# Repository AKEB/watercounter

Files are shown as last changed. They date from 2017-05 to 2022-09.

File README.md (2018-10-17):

# README #

Простая плата на базе микросхемы ESP8266 (Wemos D1 mini). Плата считает кол-во импульсов от счетчиков воды (горячей и холодной) и импульс от системы АкваСторож.
Отображение в web интерфейсе и отправка на сервер умного дома по протоколу MQTT

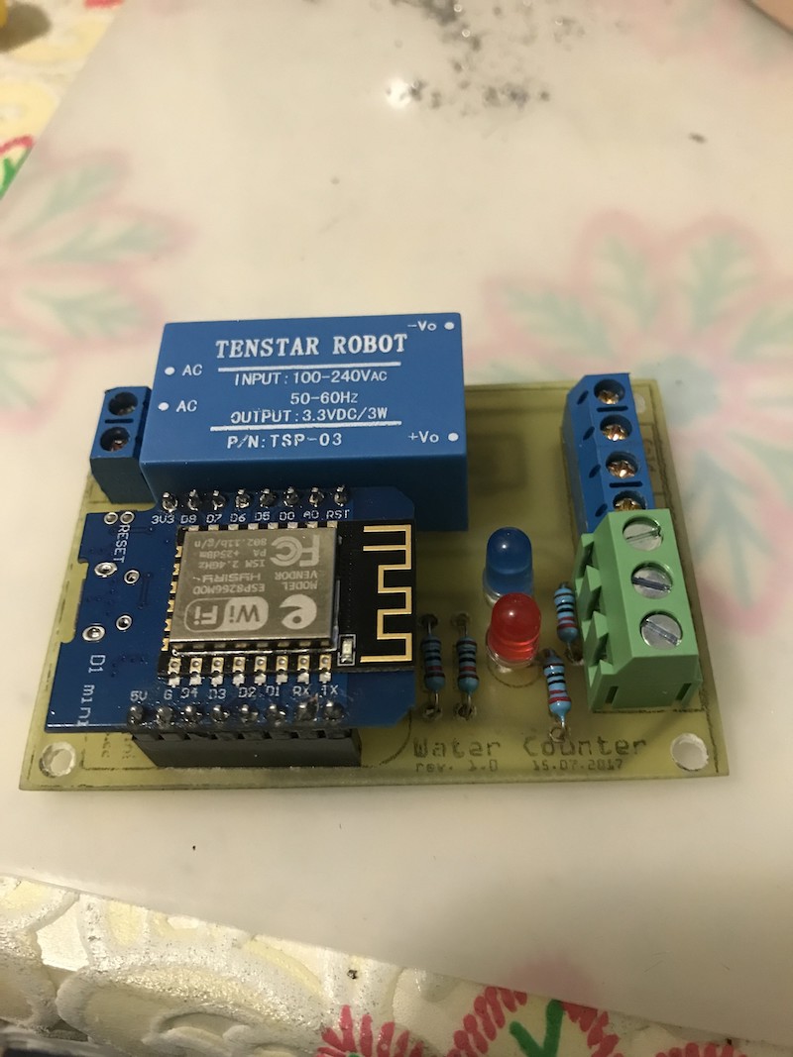
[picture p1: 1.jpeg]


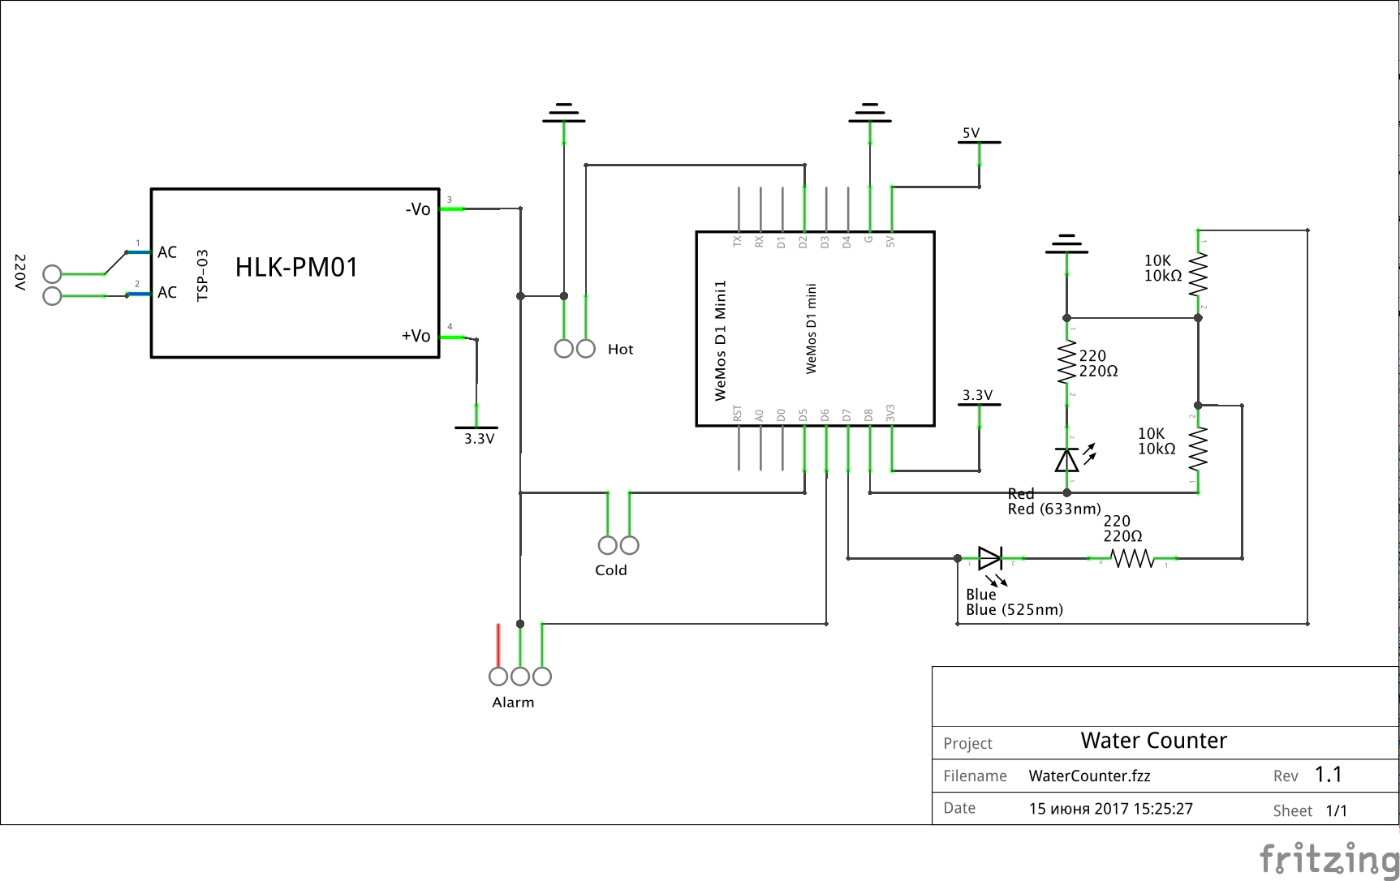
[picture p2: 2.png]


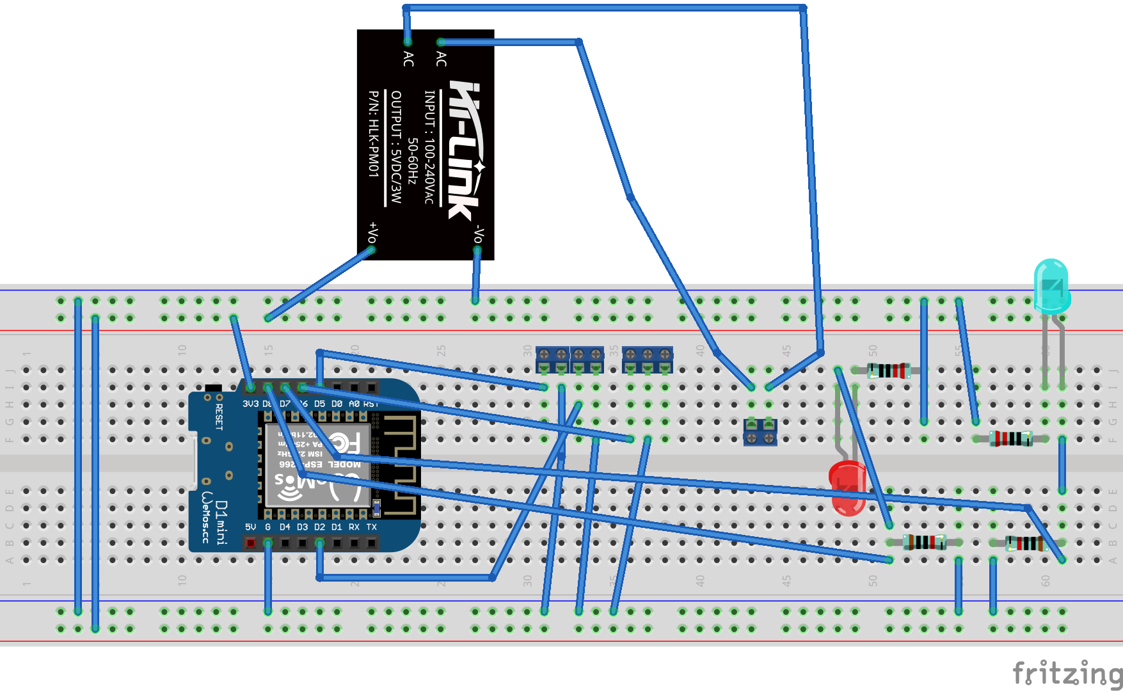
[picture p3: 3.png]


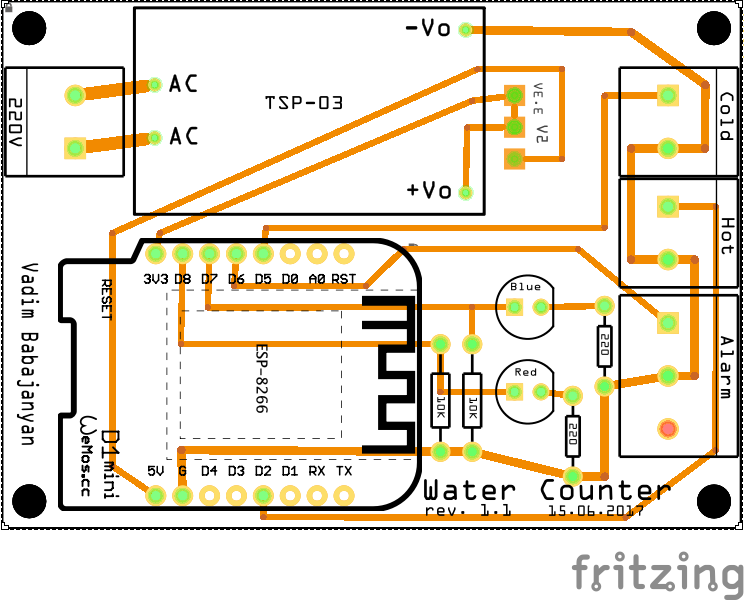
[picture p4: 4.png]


File System install https://github.com/esp8266/arduino-esp8266fs-plugin

# Распиновка #
* Красная лампа - D8 - GPIO15
* Синяя лампа - D7 - GPIO13
* Встроенная лампа - D4 - GPIO2
* Холодная вода - D5 - GPIO14
* Горячая вода - D2 - GPIO4
* ALARM - D6 - GPIO12

## Ссылки ##
* [esptool-gui](https://github.com/Rodmg/esptool-gui)
* [esptool](https://github.com/espressif/esptool)

## Код для заливки прошивки ##
```
#!bash

./esptool.py --port /dev/cu.wchusbserial1420 write_flash -fm=dio -fs=4MB 0x00000 ~/Downloads/0x00000_ESP8266_201705062105.bin

```

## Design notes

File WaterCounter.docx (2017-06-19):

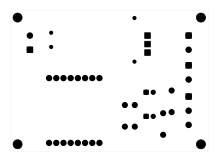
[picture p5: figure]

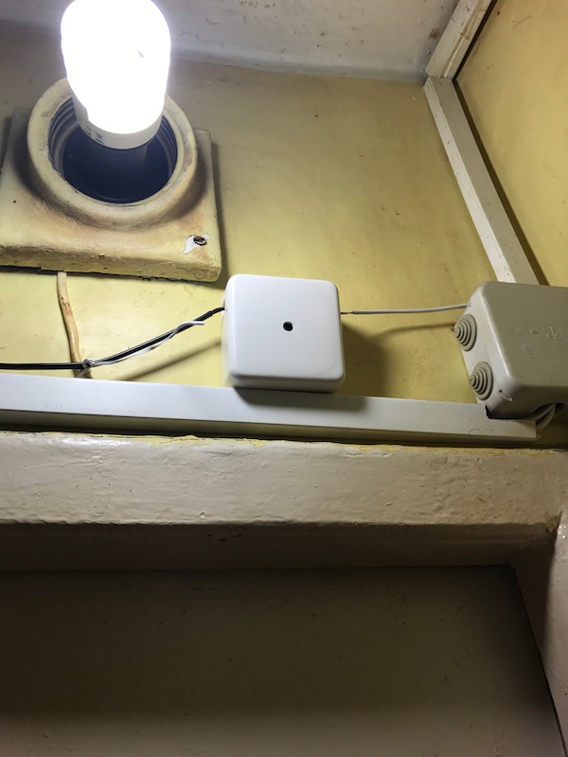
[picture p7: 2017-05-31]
Photos/IMG_0181.JPG.jpeg

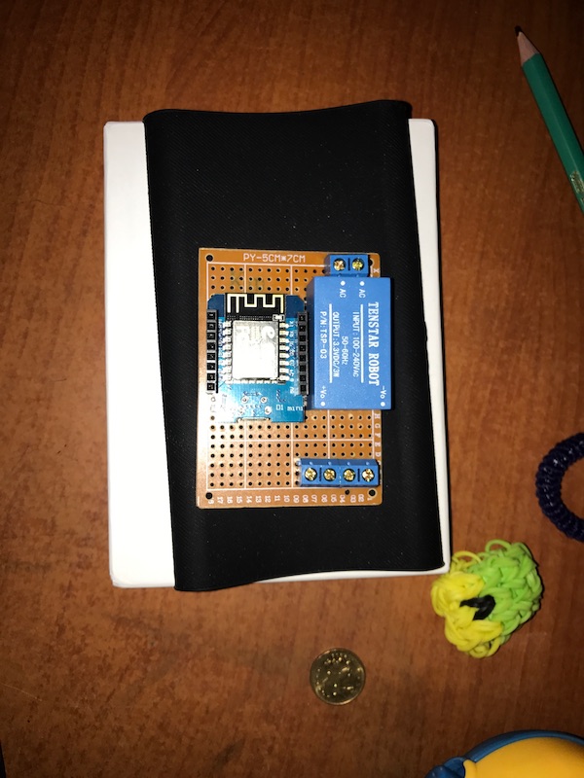
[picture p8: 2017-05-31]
Photos/IMG_0149.JPG.jpeg

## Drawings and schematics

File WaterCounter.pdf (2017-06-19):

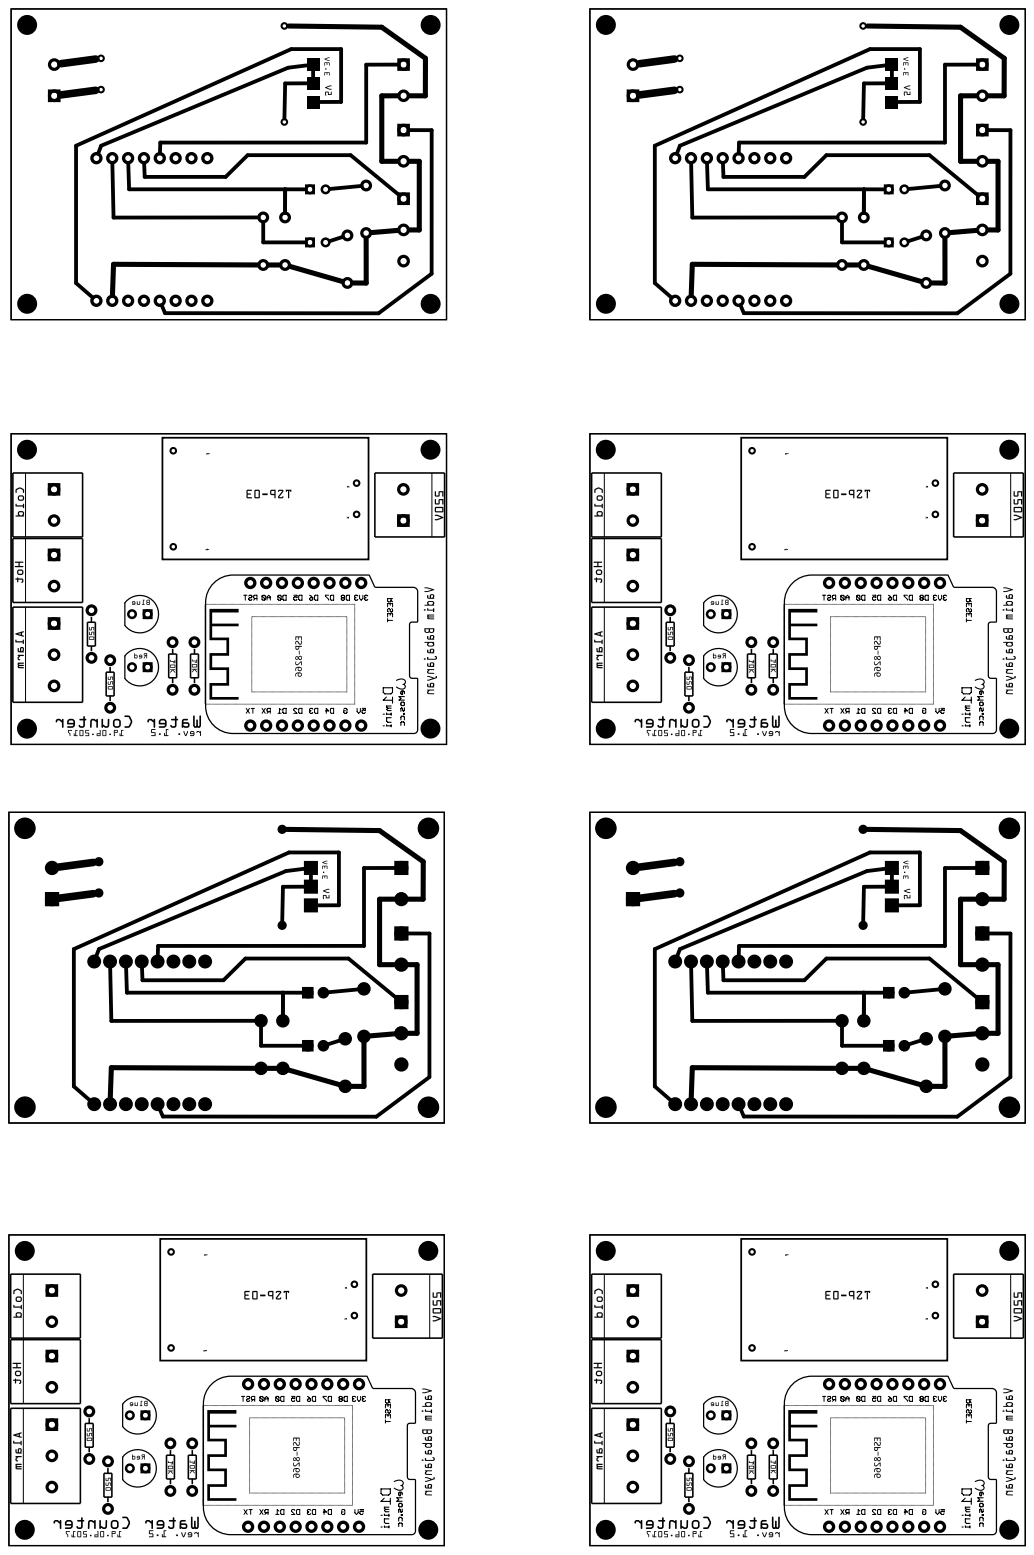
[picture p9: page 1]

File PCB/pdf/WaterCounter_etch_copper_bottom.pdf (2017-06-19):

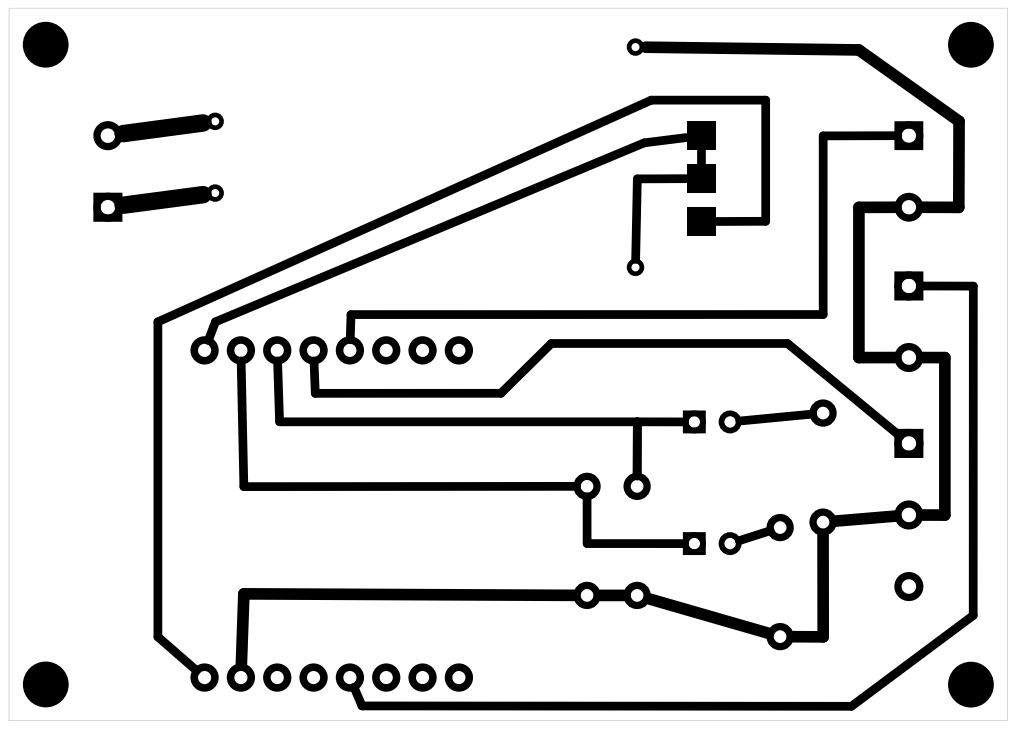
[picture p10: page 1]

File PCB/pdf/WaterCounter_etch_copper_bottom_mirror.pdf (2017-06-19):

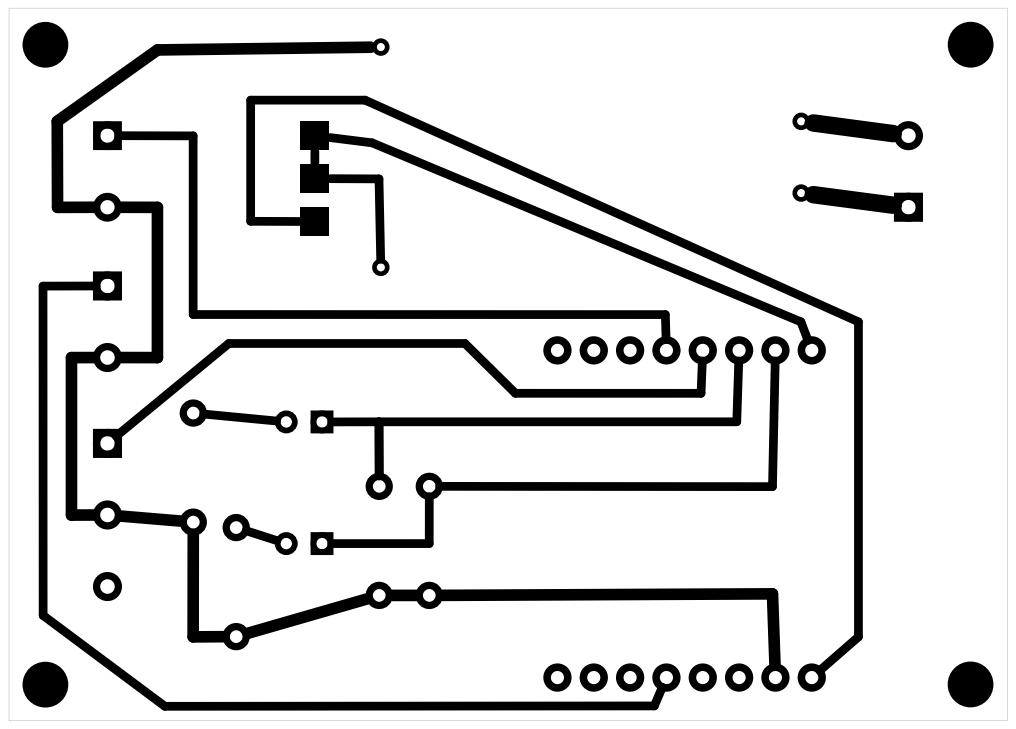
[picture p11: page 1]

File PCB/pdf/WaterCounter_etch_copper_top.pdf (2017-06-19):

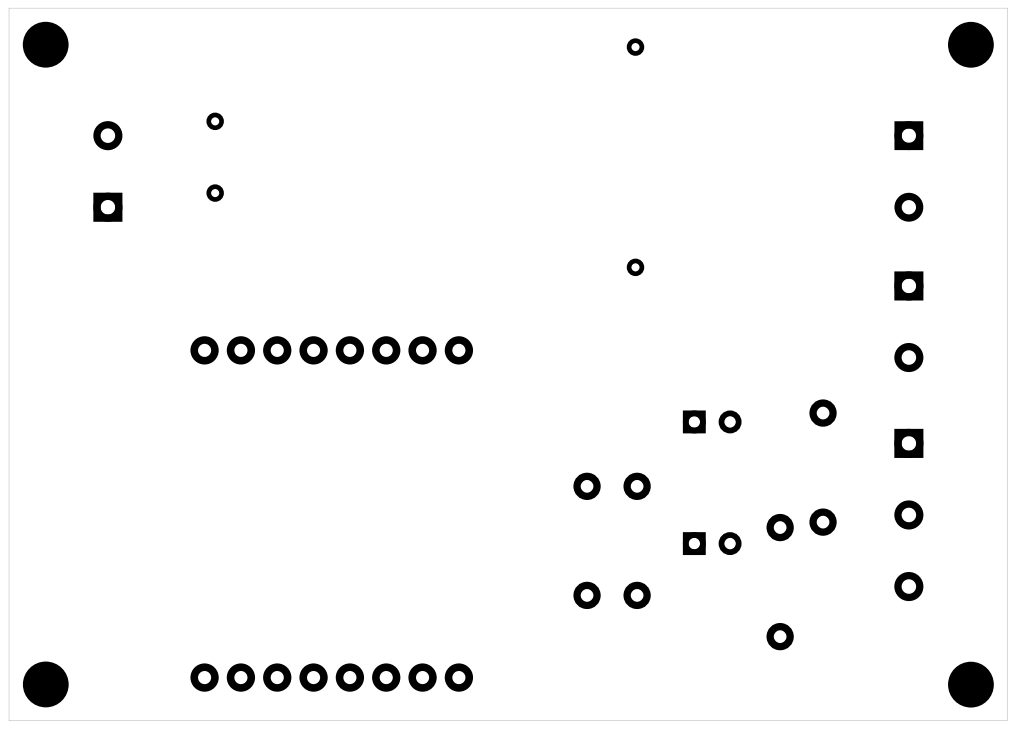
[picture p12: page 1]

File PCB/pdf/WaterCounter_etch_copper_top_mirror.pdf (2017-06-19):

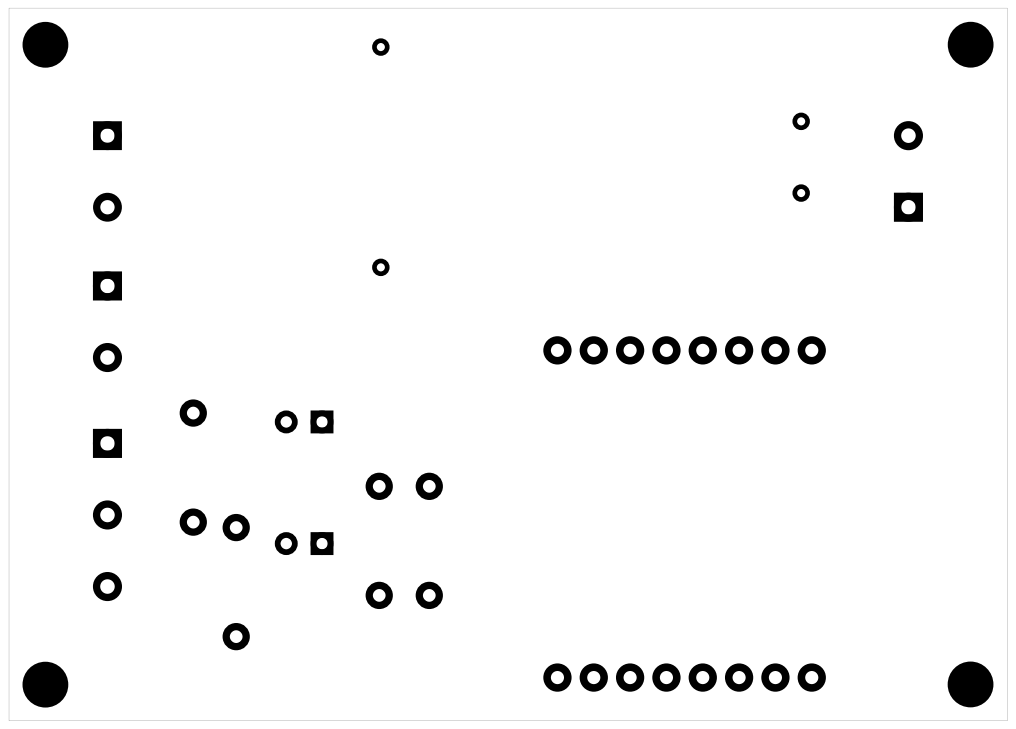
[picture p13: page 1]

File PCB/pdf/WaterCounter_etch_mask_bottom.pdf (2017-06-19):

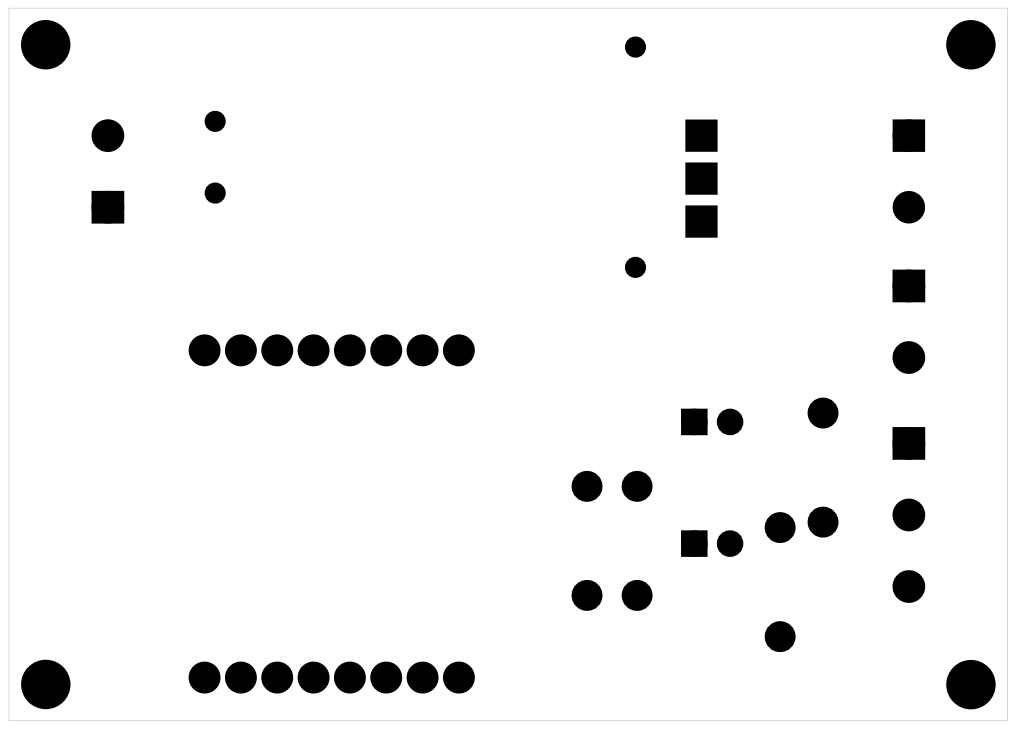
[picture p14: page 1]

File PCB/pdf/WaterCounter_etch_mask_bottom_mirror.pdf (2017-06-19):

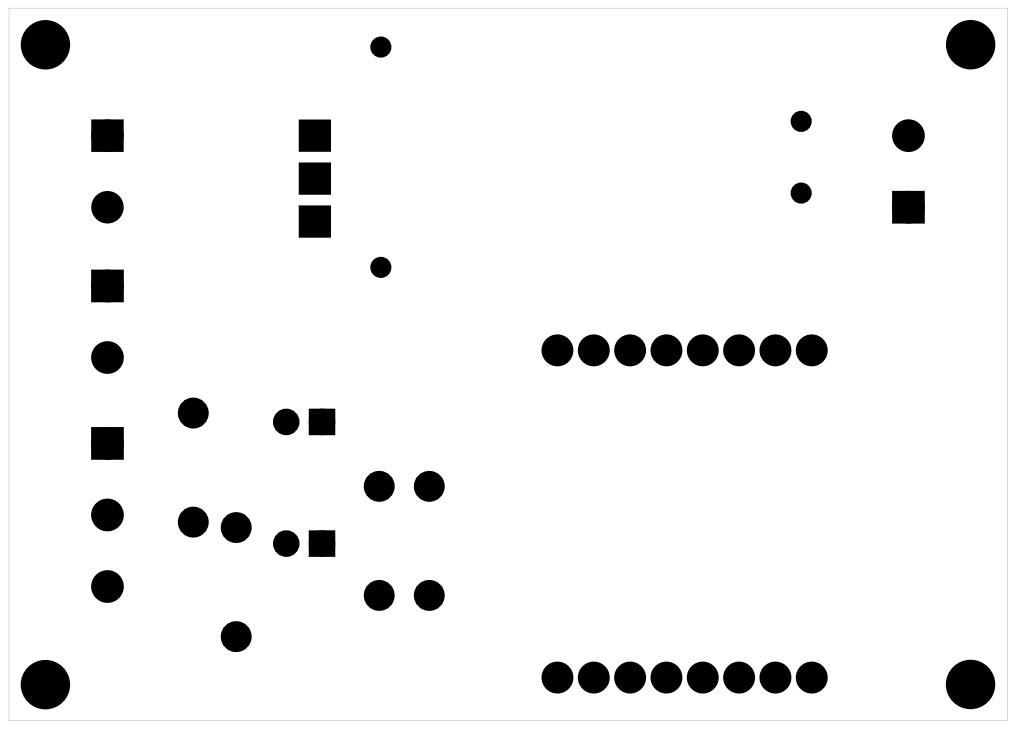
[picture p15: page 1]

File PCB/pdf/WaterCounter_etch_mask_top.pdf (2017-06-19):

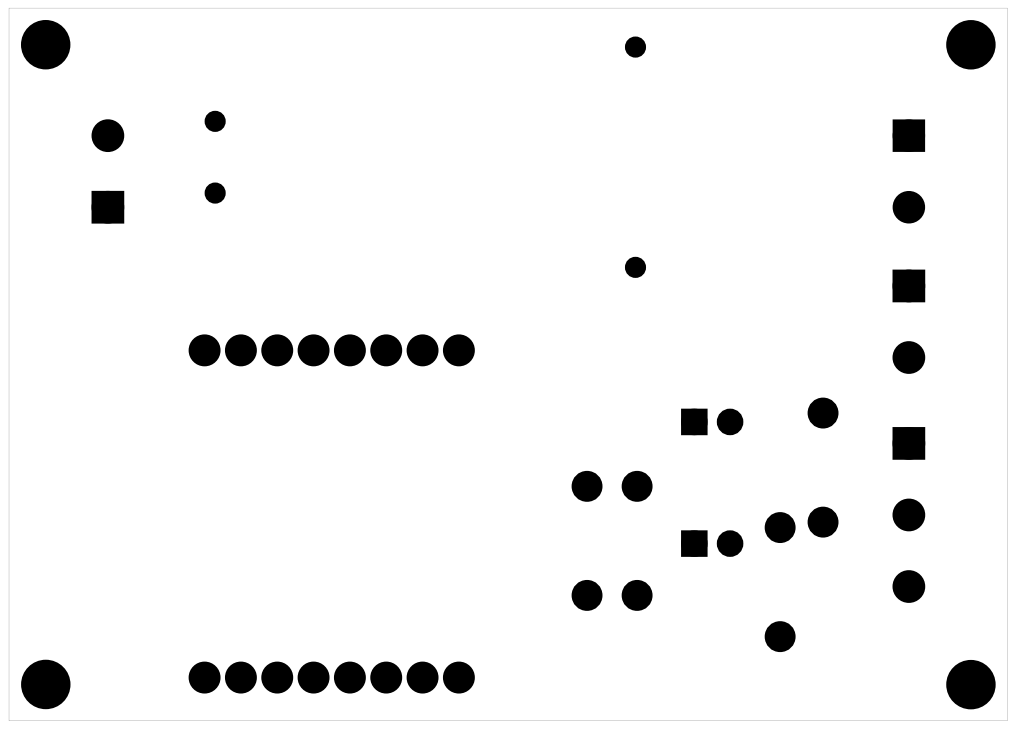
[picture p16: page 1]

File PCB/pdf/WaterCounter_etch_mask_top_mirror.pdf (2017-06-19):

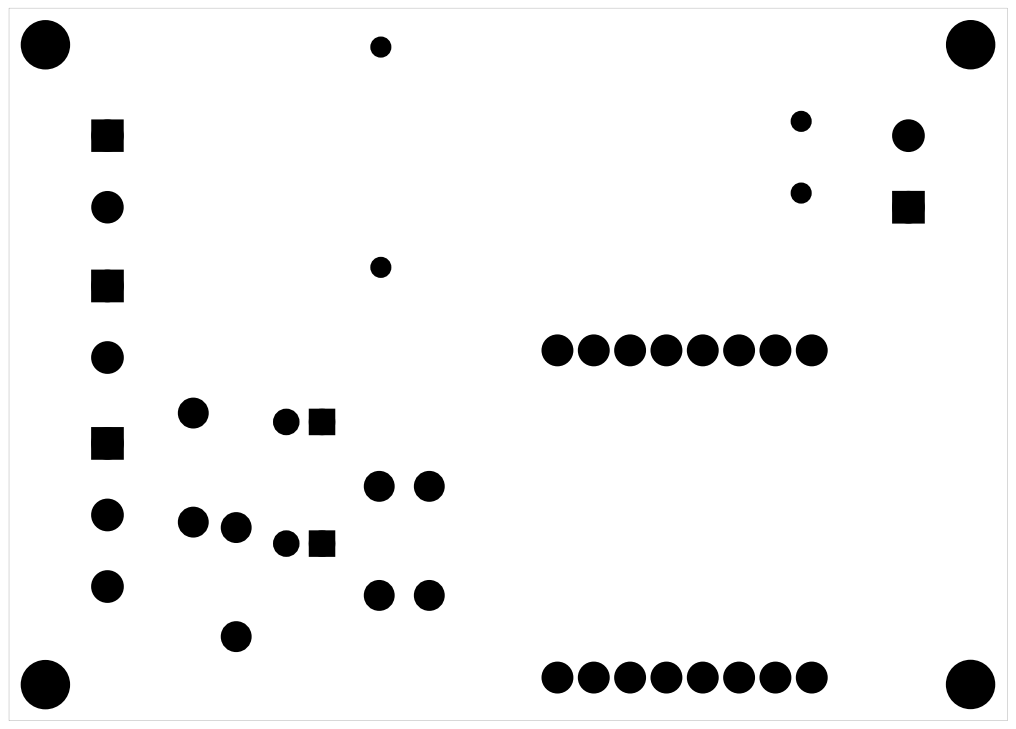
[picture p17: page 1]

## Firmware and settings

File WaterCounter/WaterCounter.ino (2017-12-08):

#include <ESP8266WiFi.h> 
#include <ESP8266WebServer.h>
#include <ESP8266SSDP.h> 
#include <FS.h>
#include <ArduinoJson.h>
#include <PubSubClient.h>
#include <ESP8266HTTPUpdateServer.h>

#define RED_LED_PIN 15
#define BLUE_LED_PIN 13
#define INNER_LED_PIN 2

#define COLD_WATER_PIN 14
#define HOT_WATER_PIN 4
#define ALARM_WATER_PIN 12

// Объект для обнавления с web страницы 
ESP8266HTTPUpdateServer httpUpdater;

// Web интерфейс для устройства
ESP8266WebServer HTTP;

// Для файловой системы
File fsUploadFile;

String _revision = "1.5"; // Версия кода

// Определяем переменные wifi
String _ssid     = "AKEB"; // Для хранения SSID
String _password = "{password}"; // Для хранения пароля сети
String _ssidAP = "WaterCounter";   // SSID AP точки доступа
String _passwordAP = ""; // пароль точки доступа
IPAddress apIP(192, 168, 0, 1);

String _http_user = "admin";
String _http_password = "0000";

String _mqtt_host     = "192.168.1.200";
int _mqtt_port     = 1883;
String _mqtt_user     = "";
String _mqtt_password     = "";

String SSDP_Name = "WaterCounter"; // Имя SSDP
int timezone = 3;               // часовой пояс GTM
int SaveCount = 0;

String jsonConfig = "{}";
int port = 80;

unsigned long ColdWaterCount = 0;
unsigned long HotWaterCount = 0;
int Alert = 0;
int ColdWaterState = 0;
int HotWaterState = 0;
int AlertState = 0;

// Делители значений счетчика
int _Div1 = 100;
int _Div2 = 100;

int HighMillis=0;
int Rollover=0;

unsigned long currentMillis;
int save_time_interval = 60*60*1000;
unsigned long save_previous_millis = 0;
int wifi_mode_time = 2000;
int wifi_mode = 0;
unsigned long wifi_mode_previous_millis = 0;
int wifi_mode_reconnect_millis = 10*60*1000;
unsigned long wifi_mode_reconnect_previous_millis = 0;
int inner_led_state = LOW;
unsigned long mqtt_reconnect_previous_millis = 0;
int mqtt_reconnect_interval = 5000;
unsigned long water_send_previous_millis = 0;
int water_send_interval = 10000;
unsigned long water_previous_millis = 0;
int water_interval = 500;
unsigned long alert_led_previous_millis = 0;
int alert_led_interval = 100;
int alert_led_state = LOW;

boolean water_changes_for_send = true;

WiFiClient wifiClientForMQTT;
PubSubClient clientForMQTT(wifiClientForMQTT);

String Log = "";

void error_log(String str) {
	error_log(str, true);
}

void error_log(String str, boolean ln) {
	Serial.print(str);
	
	if (ln) Serial.println("");
	
	Log = "[" + (String)GetTime() + "] " + str + "<br>" + Log;
	
	if (Log.length() >= 4096) {
		Log = Log.substring(0, 4096);
	}
}

void setup() {
	HTTP = ESP8266WebServer (port);
	
	Serial.begin(115200);
	error_log("");
	
	//Запускаем файловую систему
	error_log("Start File System");
	FS_init();
	
	error_log("Load Config File");
	loadConfig();
	
	error_log("Start WiFi");
	//Запускаем WIFI
	WIFI_init();
	
	error_log("Start Time module");
	// Получаем время из сети
	Time_init();

	error_log("Start MQTT module");
	MQTT_init();
	
	//Настраиваем и запускаем SSDP интерфейс
	error_log("Start SSDP");
	SSDP_init();
	
	//Настраиваем и запускаем HTTP интерфейс
	error_log("Start WebServer");
	HTTP_init();
	
	//Настраиваем и запускаем HTTP интерфейс
	error_log("Start mDNS");
	mDNS_init();
	
	error_log("Start Water module");
	Water_init();
}

void loop() {
	HTTP_loop();
	
	delay(1);
	Time_loop();
	
	WIFI_loop();

	FileConfig_loop();

	MQTT_loop();

	Water_loop();
	
}

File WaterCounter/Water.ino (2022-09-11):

void Water_init() {
	pinMode(RED_LED_PIN, OUTPUT);
	pinMode(BLUE_LED_PIN, OUTPUT);
	
	pinMode(COLD_WATER_PIN, INPUT_PULLUP);
	pinMode(HOT_WATER_PIN, INPUT_PULLUP);
	pinMode(ALARM_WATER_PIN, INPUT_PULLUP);
	
	water_changes_for_send = true;
	
	HTTP.on("/watercold", handle_Set_WaterCold);
	HTTP.on("/waterhot", handle_Set_WaterHot);
	HTTP.on("/waterAlert", handle_Set_WaterAlert);
	
}

void Water_loop() {
	
	if (currentMillis < water_send_previous_millis) water_send_previous_millis = 0;
	if(currentMillis - water_send_previous_millis >= water_send_interval) {
		water_send_previous_millis = currentMillis;
		
		if (water_changes_for_send) {
			MQTT_publish("akeb/"+ _ssidAP + "/cold",(String) ColdWaterCount);
			MQTT_publish("akeb/"+ _ssidAP + "/hot",(String) HotWaterCount);
			MQTT_publish("akeb/"+ _ssidAP + "/alert",(String) Alert);
			water_changes_for_send = false;
		}
	}
	
	if (currentMillis < water_previous_millis) water_previous_millis = 0;
	if(currentMillis - water_previous_millis >= water_interval) {
		water_previous_millis = currentMillis;
		
		int state = 0;
		state = digitalRead(COLD_WATER_PIN);
		if (state != ColdWaterState) {
			ColdWaterState = state;
			if (ColdWaterState == LOW) {
				++ColdWaterCount;
				MQTT_publish("akeb/"+ _ssidAP + "/cold",(String) ColdWaterCount);
			}
		}
		if (Alert < 1) digitalWrite(BLUE_LED_PIN, !state);
		
		state = digitalRead(HOT_WATER_PIN);
		if (state != HotWaterState) {
			HotWaterState = state;
			if (HotWaterState == LOW) {
				++HotWaterCount;
				MQTT_publish("akeb/"+ _ssidAP + "/hot",(String) HotWaterCount);
			}
		}
		if (Alert < 1) digitalWrite(RED_LED_PIN, !state);
		
		state = digitalRead(ALARM_WATER_PIN);
		if (state != AlertState) {
			AlertState = state;
			if (AlertState == LOW) {
				++Alert;
				MQTT_publish("akeb/"+ _ssidAP + "/alert",(String) Alert);
			}
		}
	}

	if (currentMillis < alert_led_previous_millis) alert_led_previous_millis = 0;
	if(currentMillis - alert_led_previous_millis >= alert_led_interval) {
		if (Alert > 0) {
			alert_led_previous_millis = currentMillis;
			alert_led_state = !alert_led_state;
			digitalWrite(RED_LED_PIN, alert_led_state);
			digitalWrite(BLUE_LED_PIN, alert_led_state);
		}
	}
}

void handle_Set_WaterAlert() {
	if(!HTTP.authenticate(_http_user.c_str(), _http_password.c_str())) return HTTP.requestAuthentication();
	error_log("handle_Set_WaterAlert disable=" + HTTP.arg("disable"));
	if (HTTP.arg("disable").toInt() > 0) {
		Alert = 0;
	}
	water_changes_for_send = true;
	saveConfig();                         // Функция сохранения данных во Flash
	HTTP.send(200, "text/plain", "OK");   // отправляем ответ о выполнении
}

void handle_Set_WaterCold() {
	if(!HTTP.authenticate(_http_user.c_str(), _http_password.c_str())) return HTTP.requestAuthentication();
	ColdWaterCount = HTTP.arg("cold").toInt();
	water_changes_for_send = true;
	saveConfig();                         // Функция сохранения данных во Flash
	HTTP.send(200, "text/plain", "OK");   // отправляем ответ о выполнении
}

void handle_Set_WaterHot() {
	if(!HTTP.authenticate(_http_user.c_str(), _http_password.c_str())) return HTTP.requestAuthentication();
	HotWaterCount = HTTP.arg("hot").toInt();
	water_changes_for_send = true;
	saveConfig();                         // Функция сохранения данных во Flash
	HTTP.send(200, "text/plain", "OK");   // отправляем ответ о выполнении
}

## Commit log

2017-05-31 Прошивка для Счетчика воды
2017-05-31 Уменьшил размер картинок
2017-05-31 Подсказка
2017-06-16 Печатная плата
    [WaterCounter.fzz]
2017-06-16 Фотографии
2017-06-16 Код Веб интерфейса платы
2017-06-16 Запись в память, только при изменении
2017-06-16 Правка Readme
2017-06-16 Увеличил ширину раздела с файлами до 240px вместо 160px
2017-06-16 Настройка для MQTT Сервера
2017-06-16 правка чисел
2017-06-19 Мелкие правки кода
2017-06-19 #3: Использовать mDNS
2017-06-19 close #2: Доступ к Веб интерфейсу по логину и паролю
2017-06-19 Маленькая правка платы
    [WaterCounter.fzz]
2017-06-19 Правка под Word
2017-06-22 Мелкие правки
2017-06-24 Убрал Telnet Вывод логов на сайт
2017-07-17 Fix #4: Делитель параметров
    [FileConfig.ino, HTTP_init.ino, WaterCounter.ino]
2017-07-17 Fixed #5: Версия в коде и вывод ее на сайте
    [FileConfig.ino, HTTP_init.ino, WaterCounter.ino]
2017-07-24 Фикс версии 1.3
2017-09-26 Перезагрузка модуля через 10 минут, после того как модуль не смог подключиться к WiFi
2017-09-26 Небольшая правка
2017-09-26 README.md отредактирован онлайн на Bitbucket
2017-09-27 Бинарник
2017-12-08 Проверка работы загаловков
2018-10-17 Описание
